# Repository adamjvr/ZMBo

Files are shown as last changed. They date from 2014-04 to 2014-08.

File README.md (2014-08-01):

ZMBo
====

ZPress Motherboard, a TinyG hardware platform for RepRap 3D printers

Update 5/28/14
Specs:
- Atmel ATSAM4E16E ARM Cortex M4 Main Processor
- Atmel ATSAMD21G18G ARM Cortex M0+ peripheral Coprocessor
- 5 Texas Instruments DRV8825 Stepper Drivers (can handle NEMA23s)
- Max/Min Endstops for 3 Axis
- PWM driven power FET channels
- 2 Thermistor channels
- 2 Thermocouple ADCs
- TinyG Firmware, 3D printing capabilities provided via coprocessor and Kinen interface.
- Offboard Expansion Port, generic GPIO expansion, and Kinen interface compatible (https://github.com/kinen/kinen/wiki)

Depreciated Specs:
Specs:
- NXP LPC1837 ARM Cortex M3 180MHZ
- 5 Allegro A4982 Stepper Drivers
- Max/Min Endstops for 3 Axis
- 5 PWM driven power FET channels
- 2 Thermistor channels
- 2 Thermocouple ADCs
- SD Card
- TinyG Firmware, adapted for 3D printing

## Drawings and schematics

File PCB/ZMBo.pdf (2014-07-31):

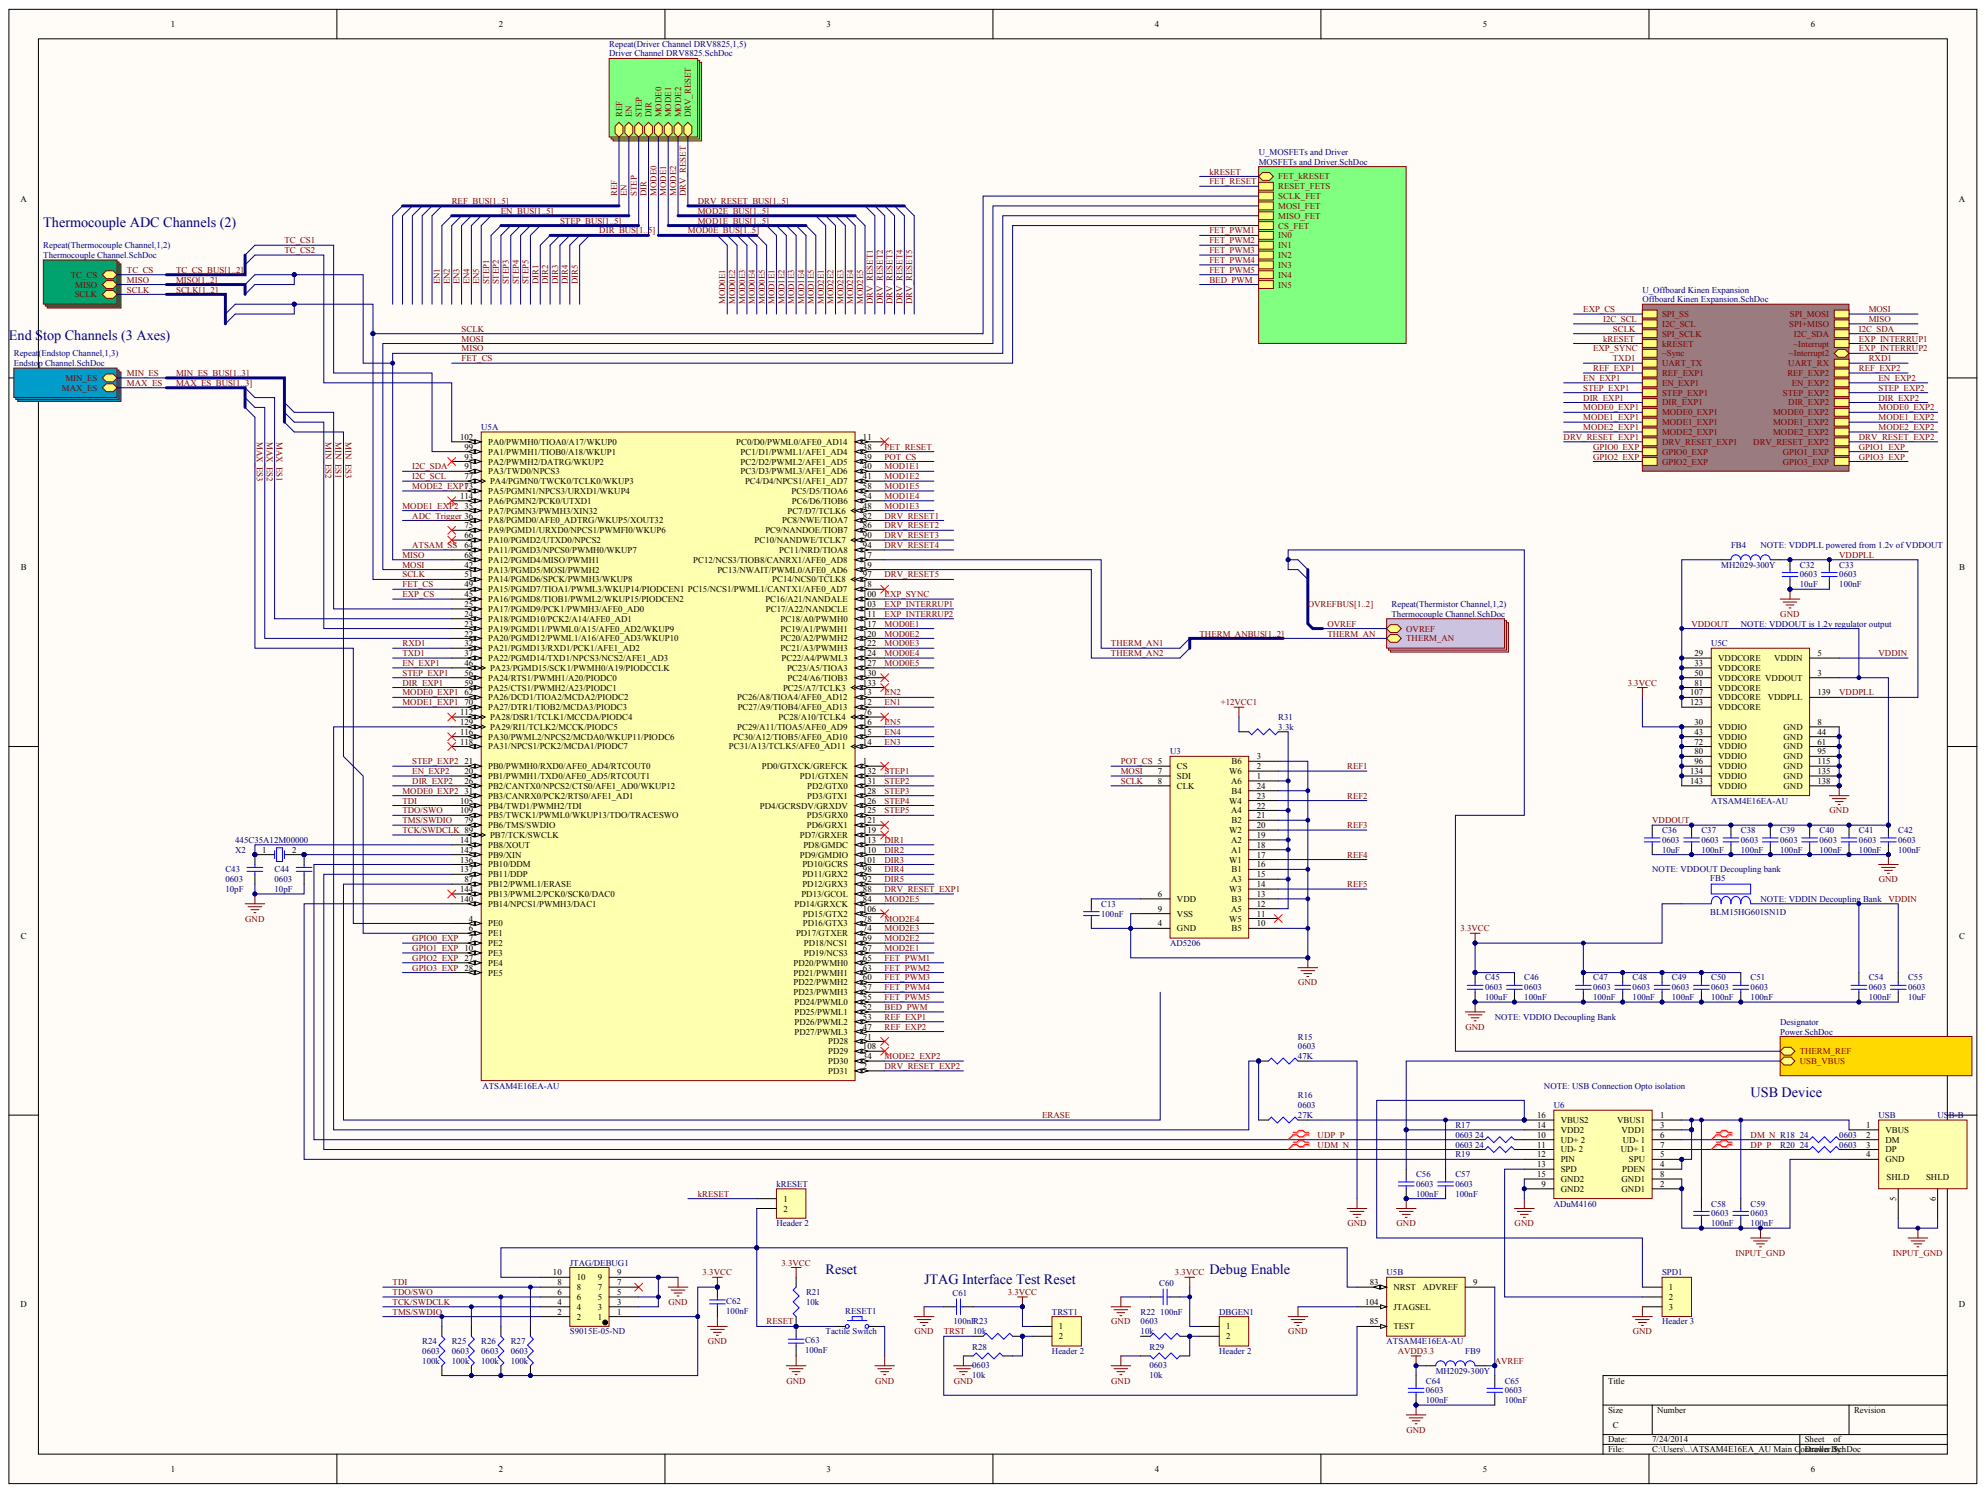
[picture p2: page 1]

DIR_BUS[1..5] SCLK | MOD0E_BUS[1..5] | FET_PWM1

End Stop Channels (3 Axes)

NOTE: VDDPLL powered from 1.2v of VDDOUT

NOTE: VDDOUT is 1.2v regulator output

RXD1 | PA21/PGMD13/RXD1/PCK1/AFE1_AD2 32

PB9/XIN 142
PB10/DDM 136
PB11/DDP 137 PD11/GRX2 | 98 DIR4

NOTE: VDDOUT Decoupling bank

NOTE: VDDIN Decoupling Bank

NOTE: VDDIO Decoupling Bank

NOTE: USB Connection Opto isolation

UDP_P | | | | R17 | | VDD2 14 | | | | VBUS 1 SHLD SHLD

UDM_N | | | | 0603 | | UD- 2 11 | 7 | DP_P R20 24 0603 | DP 3

R19 | | PIN 12 | | | GND 4

SPD 13 | | C58 0603 100nF | C59 0603 100nF
GND2 15 GND1 GND1 | 8
GND2 9 | 2

JTAG Interface Test Reset

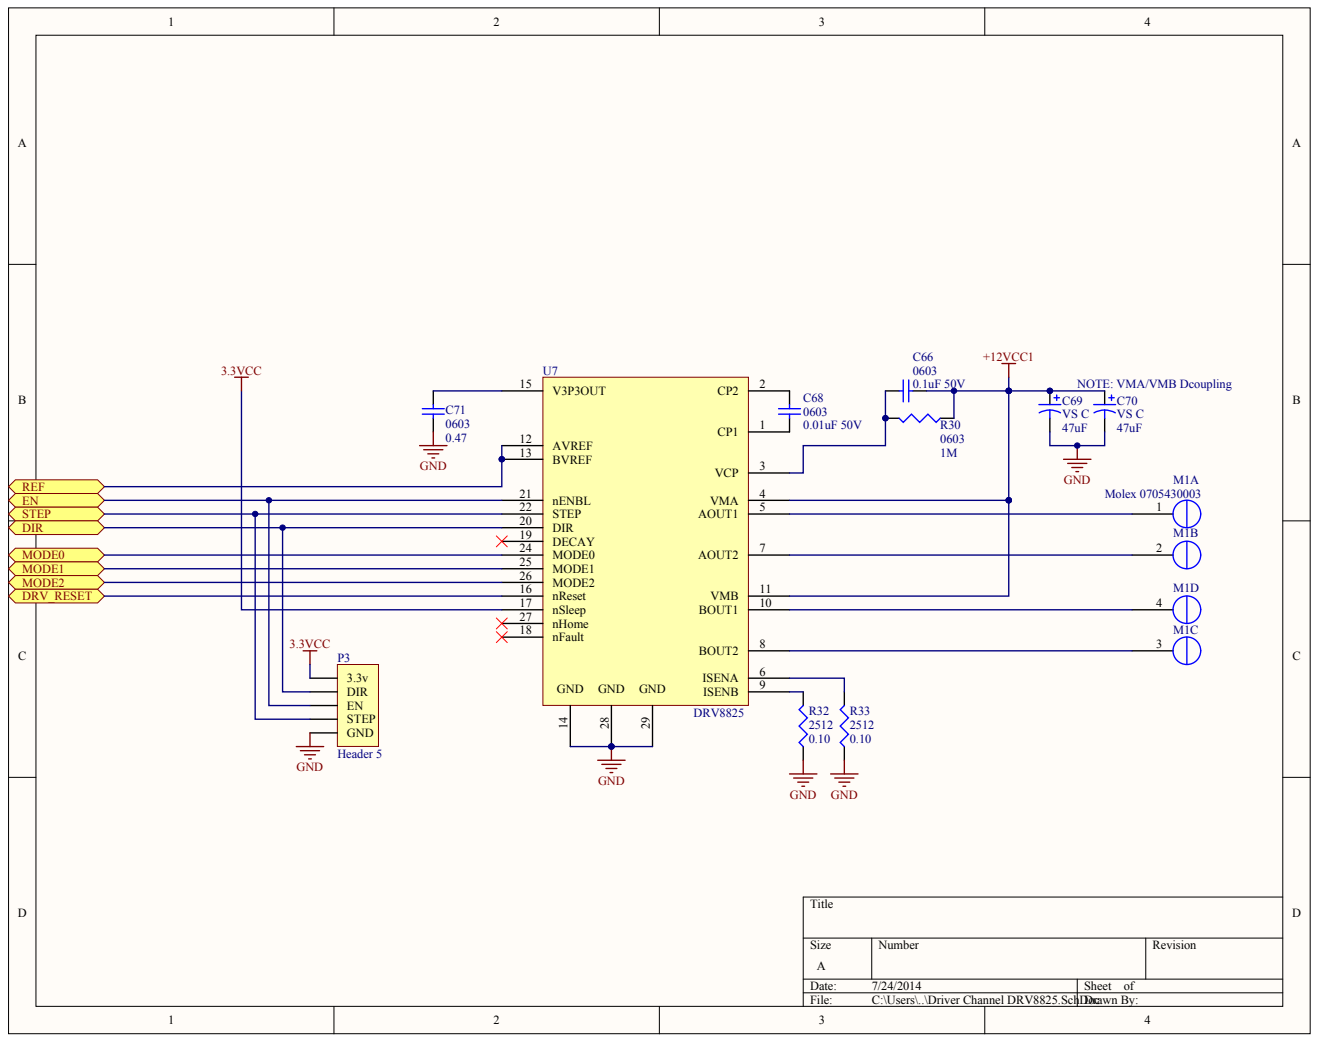
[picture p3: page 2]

C71 | | AVREF 12 | | C68 0603 0.01uF 50V

GND | | BVREF 13

MODE1 25
MODE2 26
nReset 16
nSleep 17

3.3VCC | P3 | nHome 27

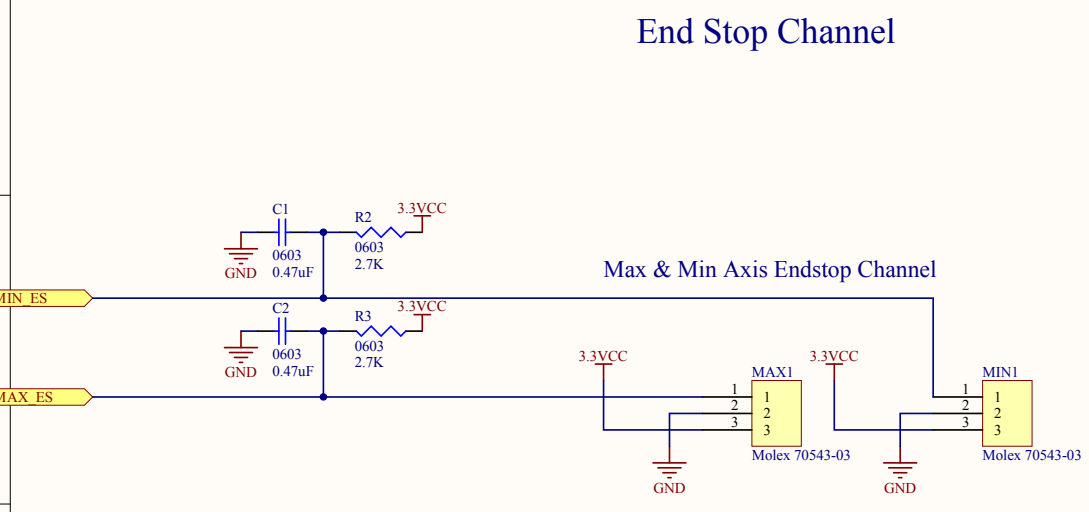
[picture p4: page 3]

Max & Min Axis Endstop Channel

C2 | 3.3VCC

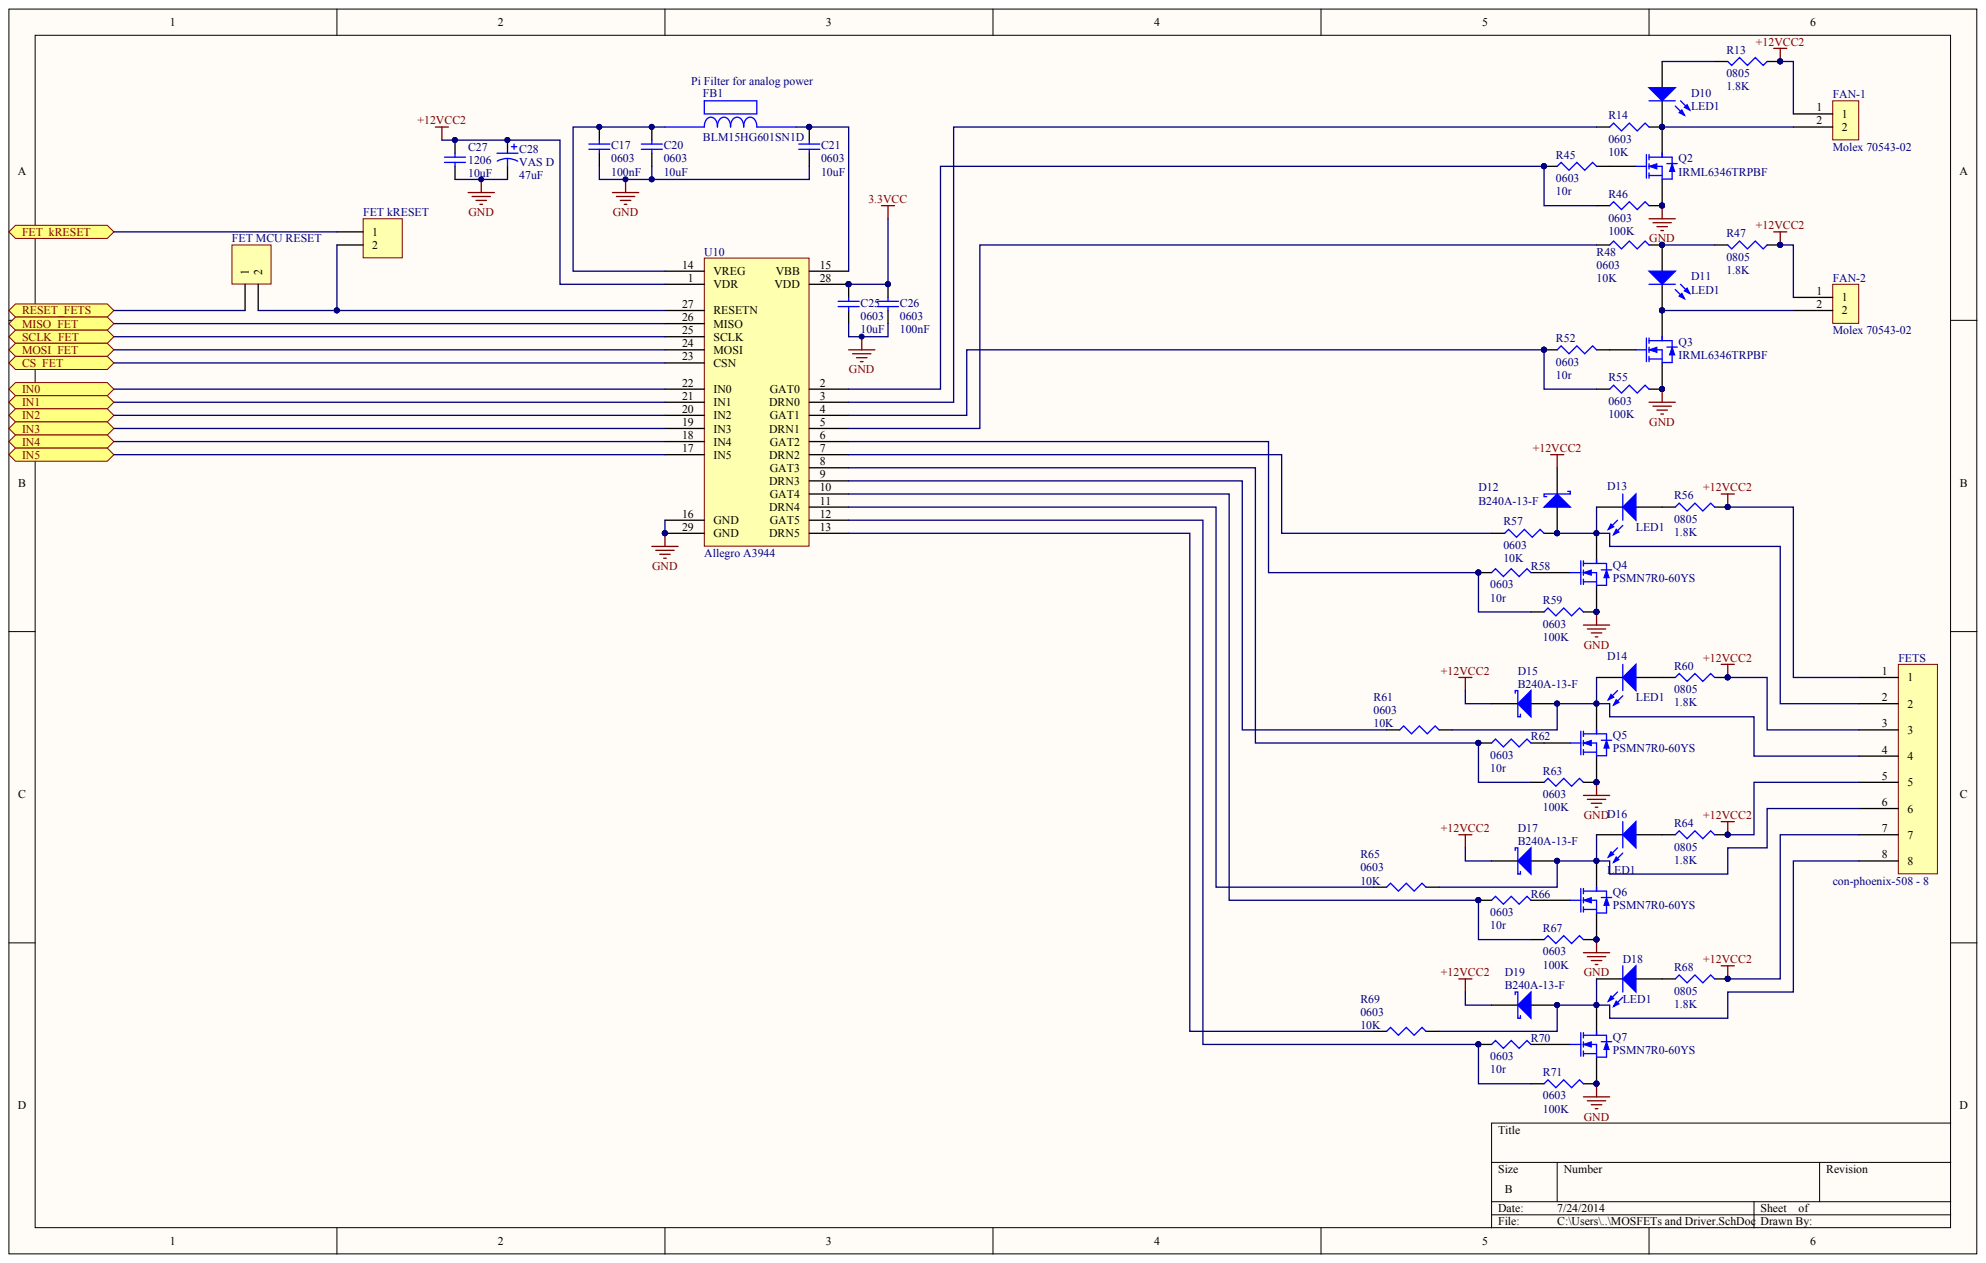
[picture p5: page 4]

Pi Filter for analog power

Size | Number | Revision B

Date: 7/24/2014 | Sheet of
File: C:\Users\..\MOSFETs and Driver.SchDoc | Drawn By:

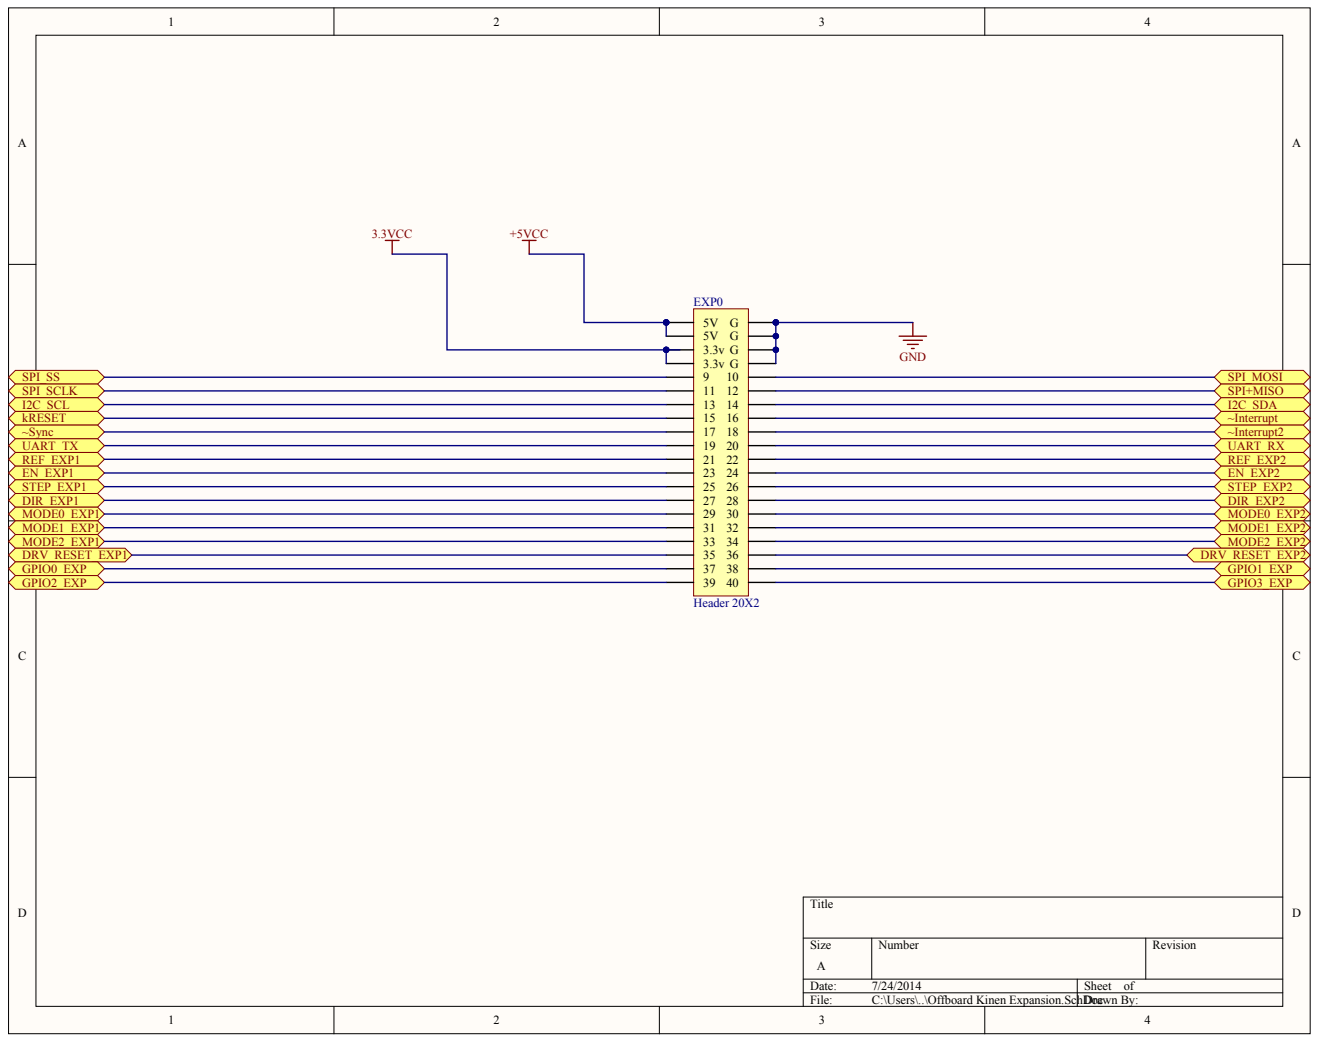
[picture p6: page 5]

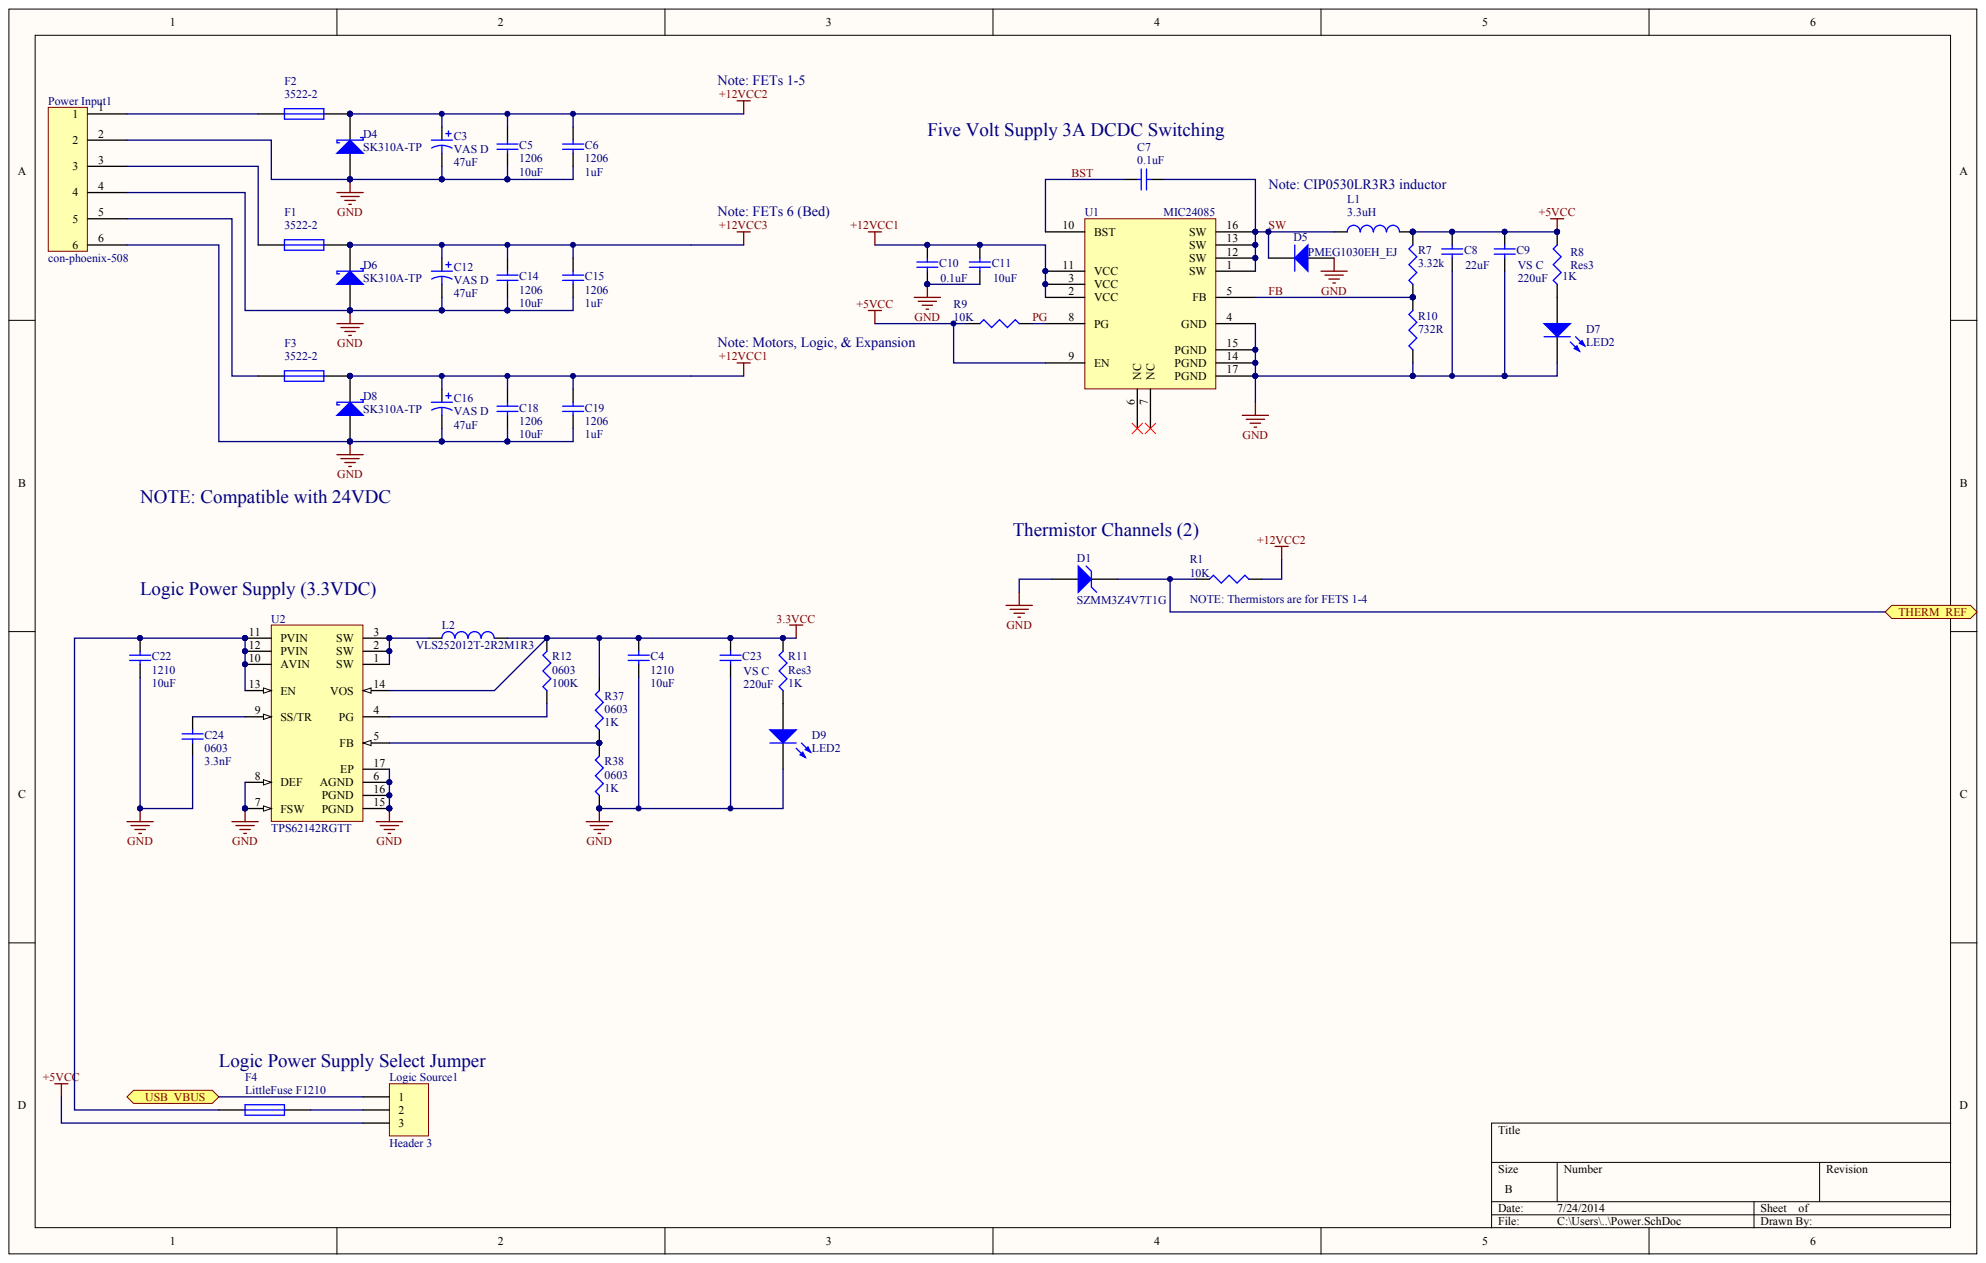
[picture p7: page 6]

Five Volt Supply 3A DCDC Switching

Note: Motors, Logic, & Expansion
+12VCC1

NOTE: Thermistors are for FETS 1-4

Logic Power Supply Select Jumper
LittleFuse F1210

Size B | Number | Revision

Date: 7/24/2014 | Sheet of
File: C:\Users\..\Power.SchDoc | Drawn By:

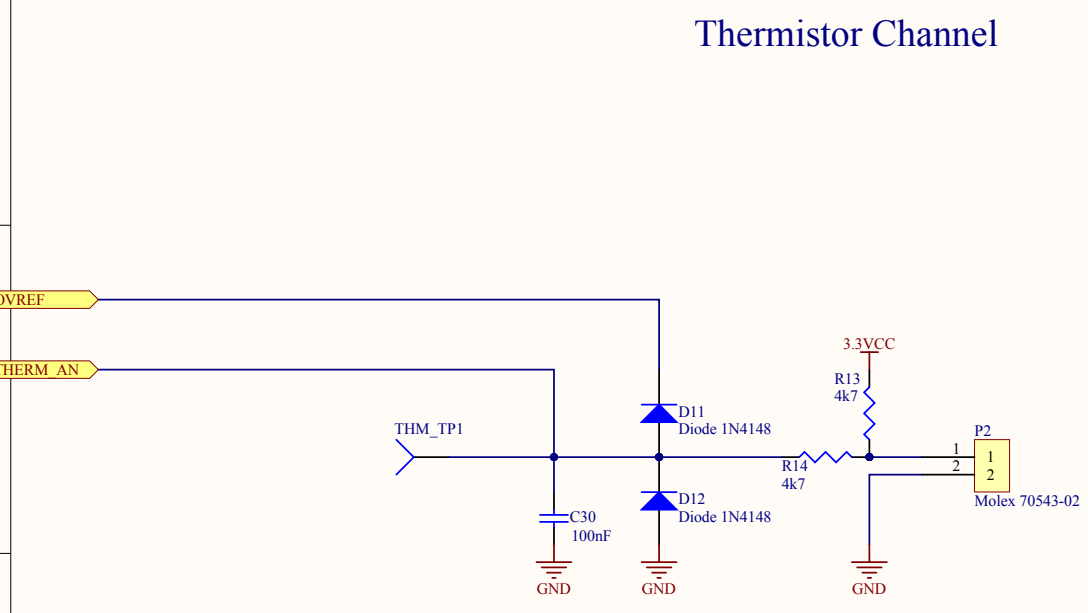
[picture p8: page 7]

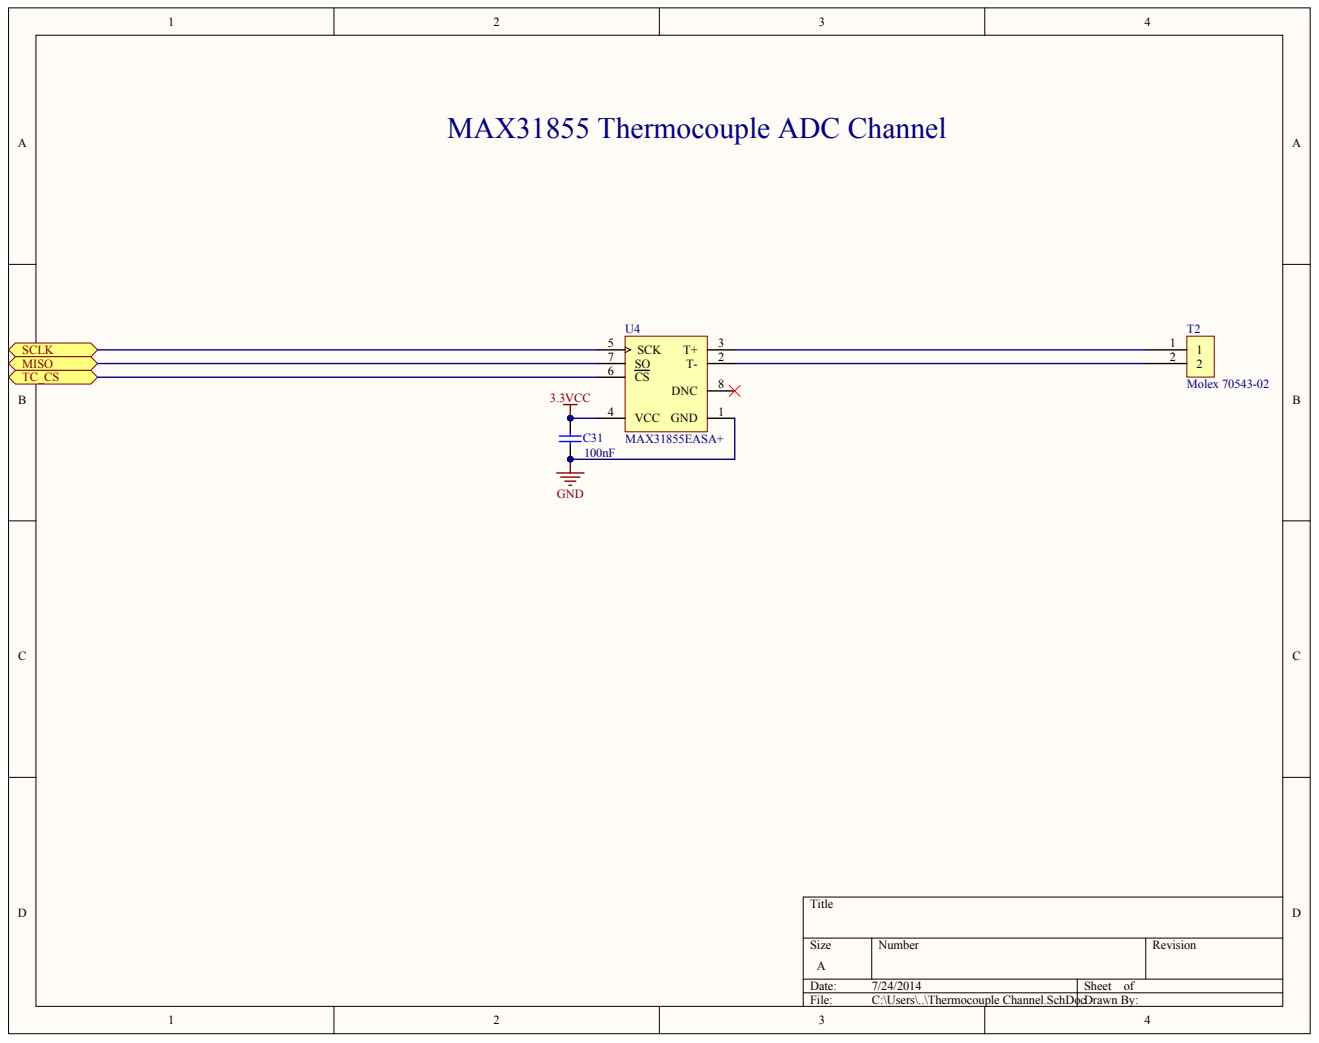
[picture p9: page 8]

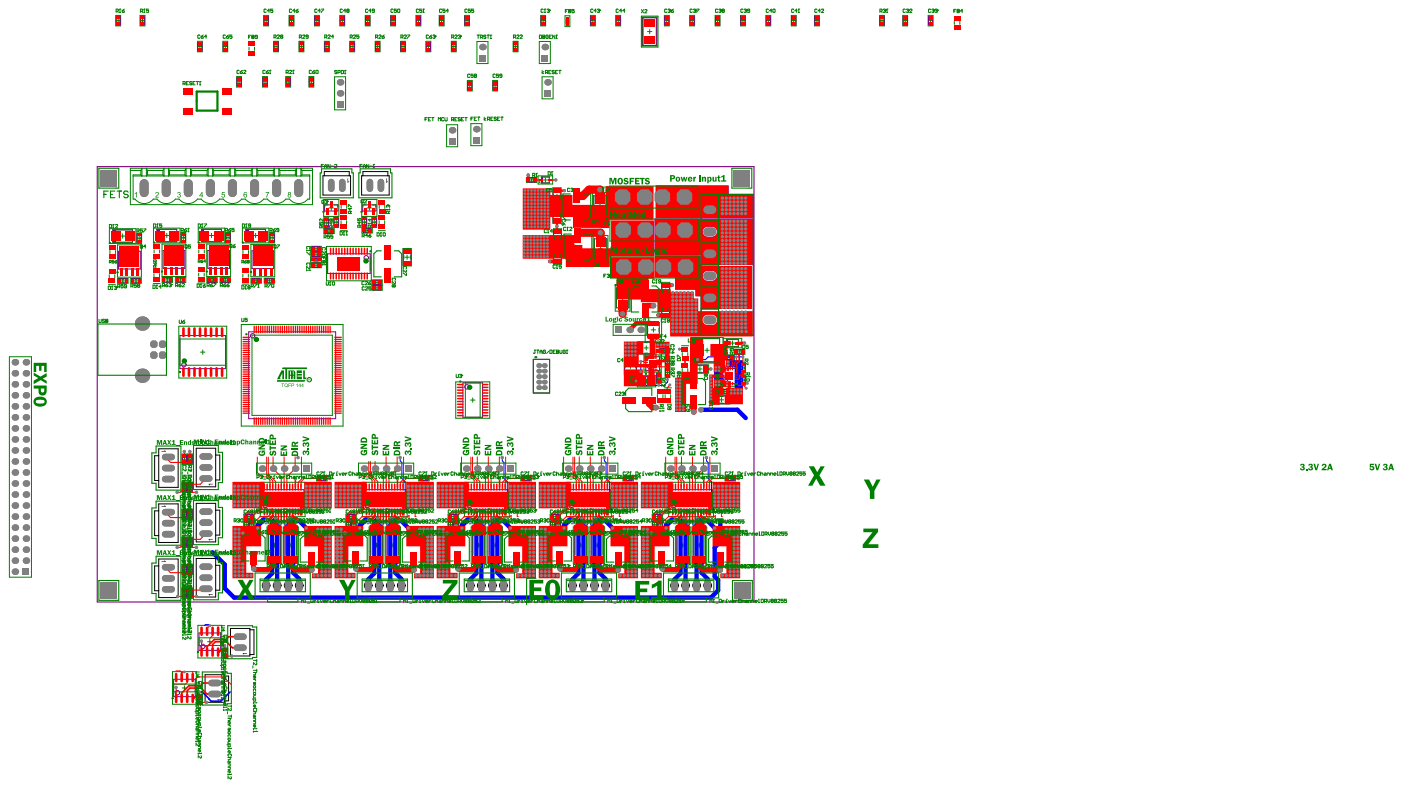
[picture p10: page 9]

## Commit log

2014-02-14 Initial Commit, Fork from RADMBo project
    Based on the progress made towards the RADMBo project, recycling all the
    basic schematics for all the subsystems of the controller.
    Revision one of the ZMBo schematic is very close to completion. What is
    left is to build the configuration schematic, this where all the
    different subsystems are set up from their "channel" schematic files.
    The configutation schematic is so that the ZMBo, ZMBo Lite, and ZMBo Pro
    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
    [Adams Altium Library.PcbLib, Adams Altium Library.SchLib, Arduino DUE Interface.SchDoc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]
2014-02-16 Full System Config
    The full board system has been setup from then many subsystems.
    Schematic almost complete.
    [Axis Channel.SchDoc, Channel Confifuration.SchDoc, FET Channel.SchDoc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]
2014-02-16 System Config
    All the subsystems have begun to be configured into the full system from
    their subsheets. Also Ryan Muller is the best!
    [Channel Confifuration.SchDoc, ZMBo Footprint Library.PcbLib]
2014-02-19 Schematic Nearly FInished
    The schematic is almost complete, all thats left to be done is to figure
    out the pinning for the LPC1830, which pins will drive all the system
    channels. A preliminary PDF of the schematic is included.
    [Axis Channel.SchDoc, Channel Confifuration.SchDoc, Endstop Channel.SchDoc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]
2014-03-07 clamping Diodes
    updated with clamping diodes on axis channel stepper drivers, as per the
    latest RAMBo schematic from Ultimachine.
    [Axis Channel.SchDoc, Channel Confifuration.SchDoc, Endstop Channel.SchDoc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]
2014-04-11 Change TO Atmel
    Switched over to Atmel CPU and DRV8825 drivers
    [ATSAM4E16EA_AU Main Controller.SchDoc, Arduino DUE Interface.SchDoc, Axis Channel.SchDoc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]
2014-04-14 Schematic update
    Significant work added to schematic, nearing completion. The entire
    project is now based on Altium's sheet hierarchy and almost fully
    channelized.
    [ATSAM4E16EA_AU Main Controller.SchDoc, Adams Altium Library.SchLib, Driver Channel DRV8825.SchDoc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]
2014-05-26 Structure Change
    Organizational structure of the schematic changed from the top sheet
    paradigm to addressing subsystems directly from the main processor
    schematic page. Makes things less modular but simpler to compile the
    schematic in Altium.
    [ATSAM4E16EA_AU Main Controller.SchDoc, Driver Channel DRV8825.SchDoc, Endstop Channel.SchDoc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]
2014-05-29 Schematic Updates
    Channel compiler errors reduced in count. Temperature control system to
    be decided
    [ATSAM4E16EA_AU Main Controller.SchDoc, Offboard Kinen Expansion.SchDoc, Power.SchDoc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]
2014-06-03 Schematic Complete
    Rev one schematic completed. Next off is to clear compiler errors then
    create the PCB.
    [ATSAM4E16EA_AU Main Controller.SchDoc, CoProcessor.SchDoc, Driver Channel DRV8825.SchDoc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]
2014-06-04 CoProcessor Schematic Fixed
    Coprocessor schematic errors fixed, the coprocessor handles all temp and
    fan PID control independently of the ATSAM4. The firmware on the
    FreeScale KL05 can and will be written to work with TinyG and other
    firmware variants.
    [ATSAM4E16EA_AU Main Controller.SchDoc, CoProcessor.SchDoc, Power.SchDoc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]
2014-06-20 Topology changeover
    changing over to a digital pot current reference topology over a PWM RC
    filter one.
    [ATSAM4E16EA_AU Main Controller.SchDoc, Adams Altium Library.PcbLib, Adams Altium Library.SchLib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]
2014-06-30 Edits
    Edits
    [ATSAM4E16EA_AU Main Controller.SchDoc, CoProcessor.SchDoc, Fan MOSFET Channel.SchDoc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]
2014-07-31 Major Changes
    The temperature control system topology is in flux, transitioning back
    to the coprocessor topology but using an Atmel ATSAMD21G18 (same as
    Arduino ZERO), since it has more SPI modules, this will allow for
    cleaner implemeation as a slave coprocessor to the ATSAM4E16E_AU.
    Stepper driver topology reimagined to be smaller clearner and allow for
    EMI filtering for OEMs. transitioned over to a FET driver topology for
    the MOSFETS, also changed over to the RAMBo's set of FETS. Power supply
    redone with bigger return copper pours for the crowbar circuit.
    [ATSAM4E16EA_AU Main Controller.SchDoc, ATSAMD21G18 CoProcessor.SchDoc, CoProcessor.SchDoc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]
